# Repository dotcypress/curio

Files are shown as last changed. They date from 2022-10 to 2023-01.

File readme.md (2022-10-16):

# Curio

Glorified Infrared Remote Control.

## Resources

- [Schematics](docs/curio.pdf)
- [Gerber files](docs/curio_pcb_rev_0x02.zip)
- [Interactive BOM](https://htmlpreview.github.io/?https://github.com/dotcypress/curio/blob/main/docs/ibom.html)
- [Rust firmware](https://github.com/dotcypress/curio-firmware)

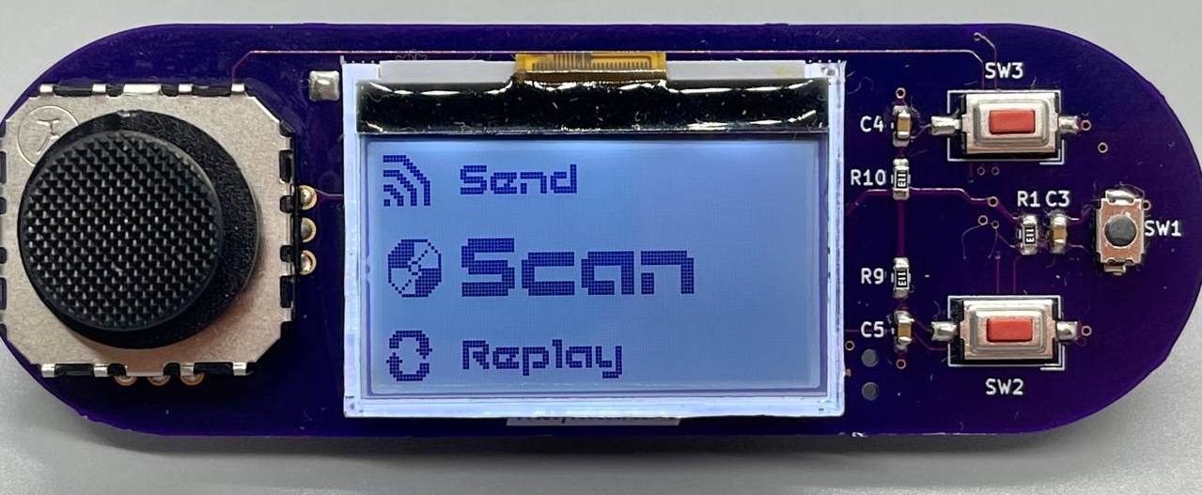
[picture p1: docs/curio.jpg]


## Credits

* [`1-Bit Icons`](https://vectorpixelstar.itch.io) by VectorPixelStar
* [`Edition 12`](https://www.dafont.com/edition-12.font) font by Designer's High
* [`BM Army`](https://www.dafont.com/bm-army.font) font by BitmapMania
* [`Nokia Cellphone FC`](https://www.dafont.com/nokia-cellphone.font) font by Zeh Fernando

## License

Licensed under either of

- Apache License, Version 2.0 ([LICENSE-APACHE](LICENSE-APACHE) or
  http://www.apache.org/licenses/LICENSE-2.0)
- MIT license ([LICENSE-MIT](LICENSE-MIT) or http://opensource.org/licenses/MIT)

at your option.

### Contribution

Unless you explicitly state otherwise, any contribution intentionally submitted
for inclusion in the work by you, as defined in the Apache-2.0 license, shall be
dual licensed as above, without any additional terms or conditions.

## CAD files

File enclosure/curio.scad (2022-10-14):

module Pcb(height=1.6) {
  length = 76.55;
  width = 25.451;

  translate([-length/2, -width/2, -height/2])
    hull()
      linear_extrude(height=height, convexity=8) 
      import(file="curio.svg");

  translate([-length/2 + 11.53, 0, 5])
    cube([10, 10, 10], center=true);
}

Pcb();

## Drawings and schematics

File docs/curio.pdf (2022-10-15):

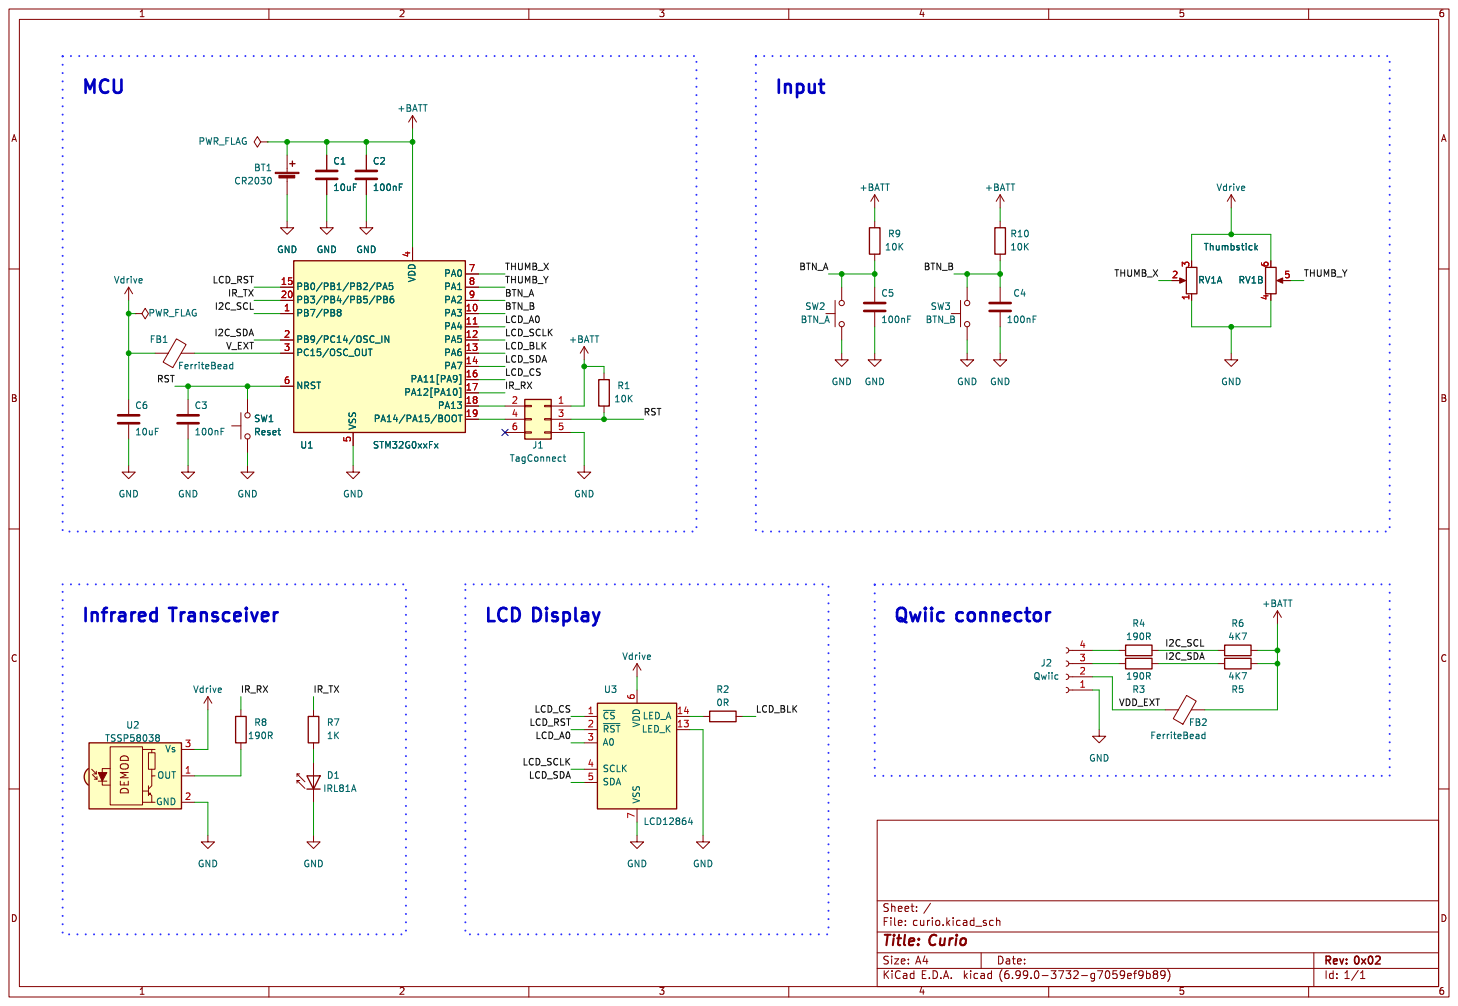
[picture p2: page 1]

5 NRST 6 PA0 7 PA1 8 PA2 9 U1 STM32G0xxFx DEMOD OUT 1 GND 2 Vs 3 U2 TSSP58038 Vdrive GND GND

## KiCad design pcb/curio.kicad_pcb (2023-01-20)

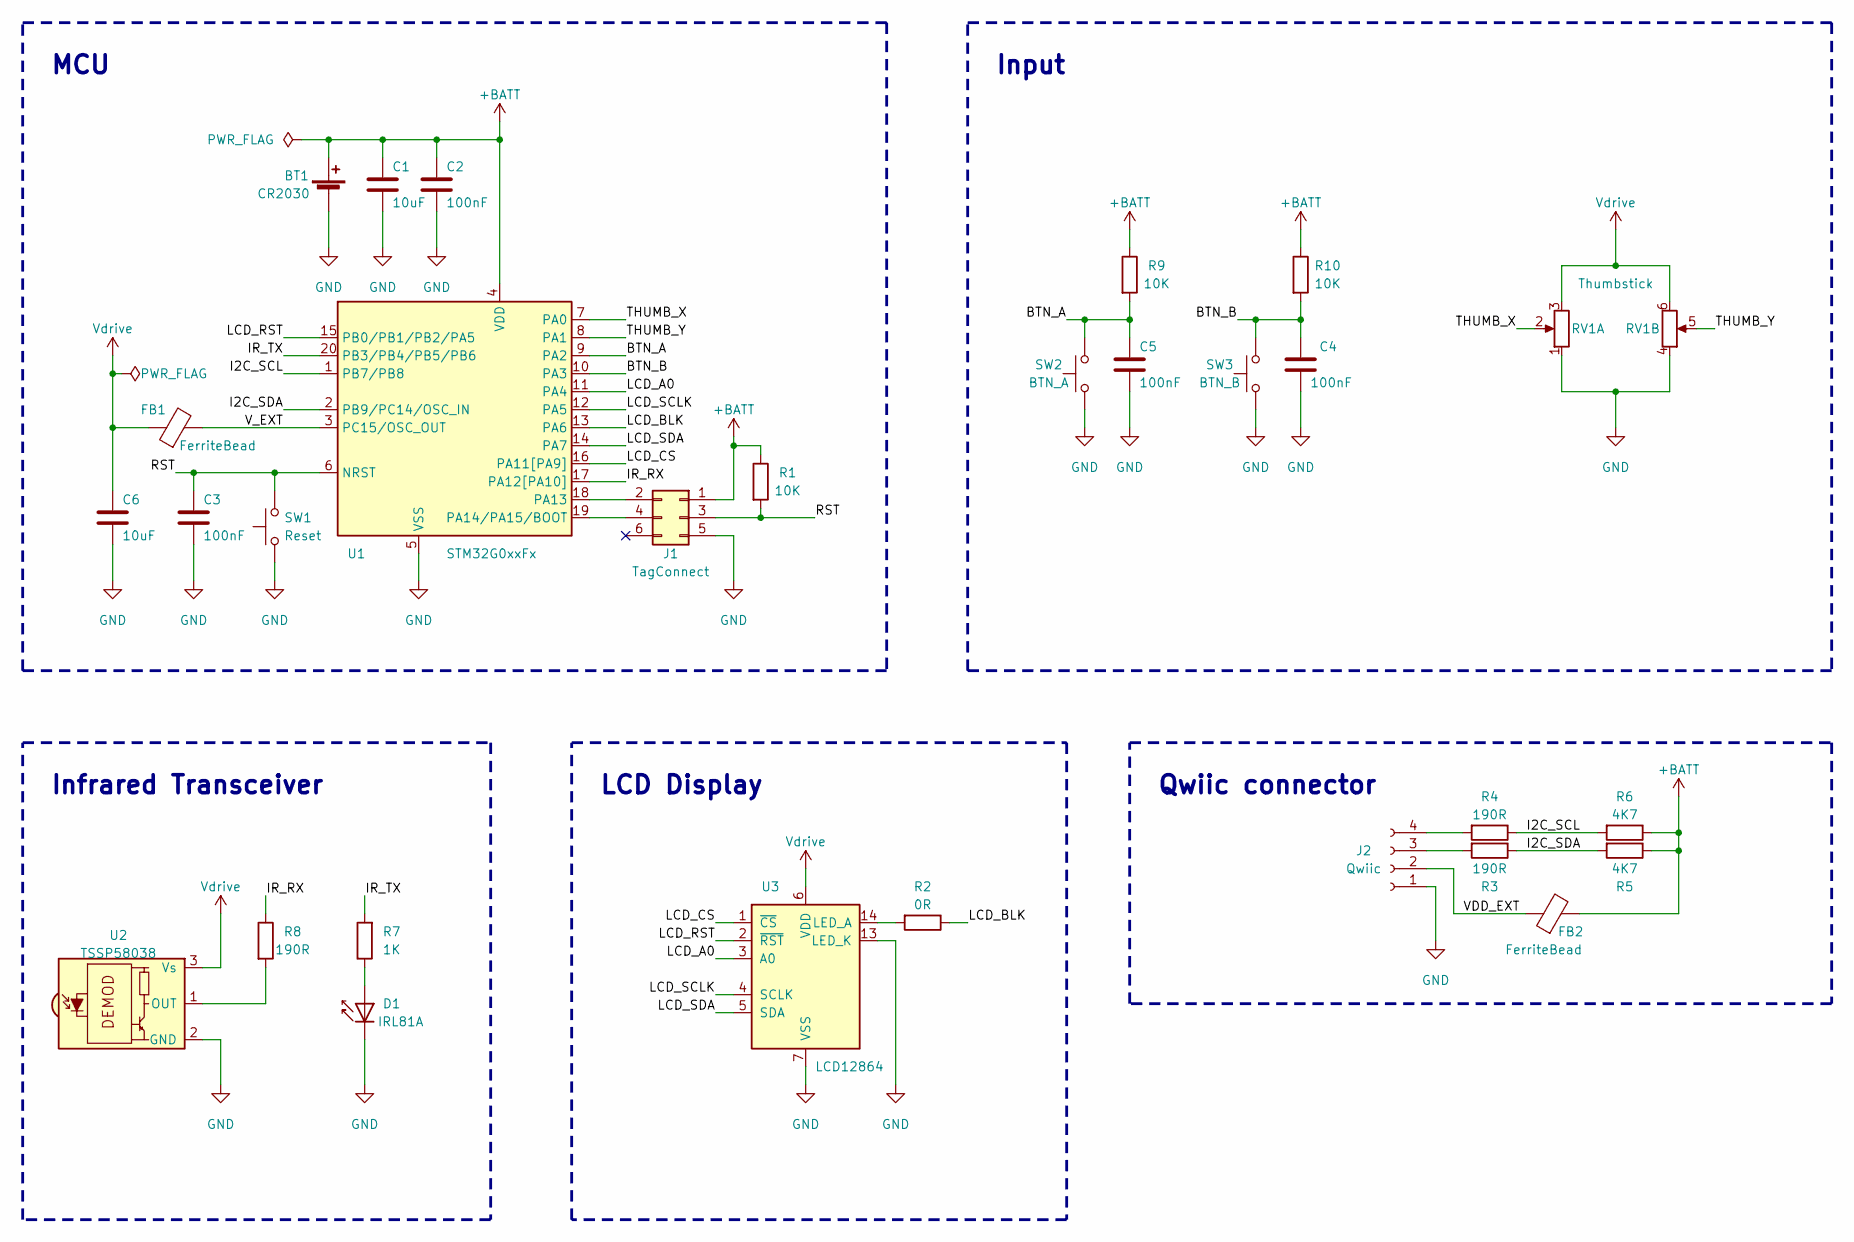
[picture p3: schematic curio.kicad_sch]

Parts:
BT1: CR2030; BatteryHolder-Lynx-BAT-HLD-001
C1, C6: 10uF; C_0603_1608Metric
C2, C3, C4, C5: 100nF; C_0603_1608Metric
D1: IRL81A; LED_SideEmitter_Rectangular_W4.5mm_H1.6mm
FB1, FB2: FerriteBead; R_0603_1608Metric
J1: TagConnect; Tag-Connect_TC2030-IDC-NL_2x03_P1.27mm_Vertical
J2: Qwiic; JST_SH_SM04B-SRSS-TB_1x04-1MP_P1.00mm_Horizontal
R1, R9, R10: 10K; R_0603_1608Metric
R2: 0R; R_0603_1608Metric
R3, R4, R8: 190R; R_0603_1608Metric
R5, R6: 4K7; R_0603_1608Metric
R7: 1K; R_0603_1608Metric
RV1: Thumbstick
SW1: Reset; R_1206_3216Metric_Pad1.30x1.75mm_HandSolder
SW2: BTN_A; SW_DIP_SPSTx01_Slide_6.7x4.1mm_W6.73mm_P2.54mm_LowProfile_J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
SW3: BTN_B; SW_DIP_SPSTx01_Slide_6.7x4.1mm_W6.73mm_P2.54mm_LowProfile_J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
U1: STM32G0xxFx; TSSOP-20_4.4x6.5mm_P0.65mm
U2: TSSP58038; Vishay_MINICAST-3Pin
U3: LCD12864; LCD_FPC_1x14_P0.80mm

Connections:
+BATT: BT1.1 (+), C1.1, C2.1, FB2.2, J1.1, R1.1, R5.1, R6.1, R9.1, R10.1, U1.4 (VDD)
/BTN_A: C5.1, R9.2, SW2.2, U1.9 (PA2)
/BTN_B: C4.1, R10.2, SW3.2, U1.10 (PA3)
/I2C_SCL: R4.1, R6.2, U1.1 (PB7/PB8)
/I2C_SDA: R3.1, R5.2, U1.2 (PB9/PC14/OSC_IN)
/IR_RX: R8.1, U1.17 (PA12[PA10])
/IR_TX: R7.2, U1.20 (PB3/PB4/PB5/PB6)
/LCD_A0: U1.11 (PA4), U3.3 (A0)
/LCD_BLK: R2.1, U1.13 (PA6)
/LCD_CS: U1.16 (PA11[PA9]), U3.1 (~CS)
/LCD_RST: U1.15 (PB0/PB1/PB2/PA5), U3.2 (~RST)
/LCD_SCLK: U1.12 (PA5), U3.4 (SCLK)
/LCD_SDA: U1.14 (PA7), U3.5 (SDA)
/RST: C3.1, J1.3, R1.2, SW1.2, U1.6 (NRST)
/THUMB_X: RV1.2, U1.7 (PA0)
/THUMB_Y: RV1.5, U1.8 (PA1)
/VDD_EXT: FB2.1, J2.2
/V_EXT: FB1.2, U1.3 (PC15/OSC_OUT)
GND: BT1.2 (-), C1.2, C2.2, C3.2, C4.2, C5.2, C6.2, D1.1 (K), J1.5, J2.1, RV1.1, RV1.4, SW1.1, SW2.1, SW3.1, U1.5 (VSS), U2.2 (GND), U3.7 (VSS), U3.13 (LED_K)
unnamed: D1.2 (A), R7.1
unnamed: J1.2, U1.18 (PA13)
unnamed: J1.4, U1.19 (PA14/PA15/BOOT)
unnamed: J2.3, R3.2
unnamed: J2.4, R4.2
unnamed: R8.2, U2.1 (OUT)
unnamed: R2.2, U3.14 (LED_A)
Vdrive: C6.1, FB1.1, RV1.3, RV1.6, U2.3 (Vs), U3.6 (VDD)

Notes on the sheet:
Input
MCU
Qwiic connector
LCD Display
Infrared Transceiver

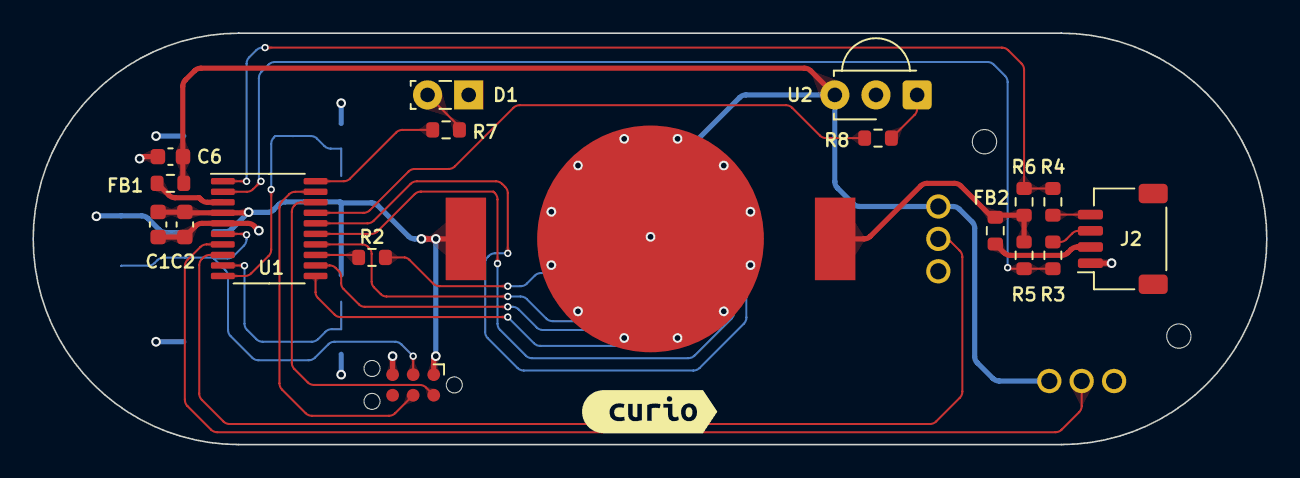
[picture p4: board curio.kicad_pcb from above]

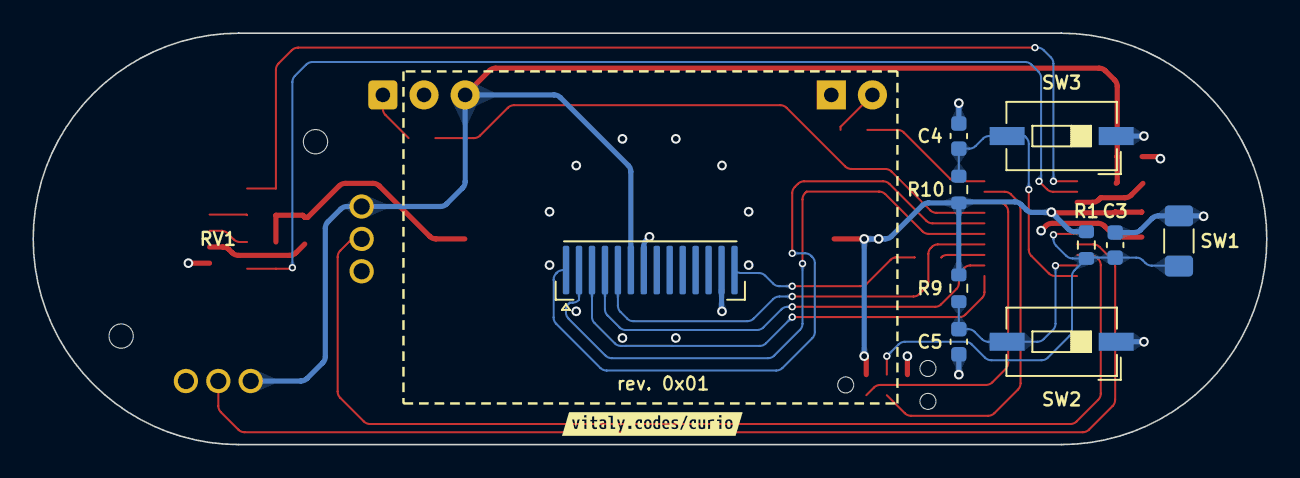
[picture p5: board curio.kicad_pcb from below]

Board: 4 copper layers, 76.2 x 25.4 mm, 31 parts (12 on the bottom side), 27 nets.

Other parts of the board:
kibuzzard-633E88B5: G***; kibuzzard-633E88B5
kibuzzard-633E88FC: G***; kibuzzard-633E88FC

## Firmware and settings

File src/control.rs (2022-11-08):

use crate::*;
use hal::analog::adc;

#[derive(Debug)]
pub enum Button {
    A,
    B,
    Up,
    Right,
    Down,
    Left,
}

pub struct Control {
    adc: adc::Adc,
    vbat: adc::VBat,
    btn_a: ButtonA,
    btn_b: ButtonB,
    thumb_x: ThumbX,
    thumb_y: ThumbY,
}

impl Control {
    pub fn new(
        btn_a: ButtonA,
        btn_b: ButtonB,
        thumb_x: ThumbX,
        thumb_y: ThumbY,
        adc: ADC,
        rcc: &mut Rcc,
    ) -> Self {
        let mut adc = adc.constrain(rcc);
        adc.set_sample_time(adc::SampleTime::T_80);
        adc.set_precision(adc::Precision::B_12);
        adc.set_oversampling_shift(24);
        adc.set_oversampling_ratio(adc::OversamplingRatio::X_8);
        adc.oversampling_enable(true);

        let mut vbat = adc::VBat::new();
        vbat.enable(&mut adc);

        adc.calibrate();
        Self {
            vbat,
            btn_a,
            btn_b,
            adc,
            thumb_x,
            thumb_y,
        }
    }

    pub fn battery_voltage(&mut self) -> u16 {
        self.adc.read_voltage(&mut self.vbat).unwrap_or_default() * 3
    }

    pub fn read_buttons(&mut self) -> Option<Button> {
        if self.btn_a.is_low().unwrap_or_default() {
            return Some(Button::A);
        }
        if self.btn_b.is_low().unwrap_or_default() {
            return Some(Button::B);
        }
        None
    }

    pub fn read_dpad(&mut self) -> Option<Button> {
        let (x, y) = self.read_thumb();
        if x > 32 {
            Some(Button::Right)
        } else if x < -32 {
            Some(Button::Left)
        } else if y > 32 {
            Some(Button::Up)
        } else if y < -32 {
            Some(Button::Down)
        } else {
            None
        }
    }

    pub fn read_thumb(&mut self) -> (i8, i8) {
        (
            self.adc.read(&mut self.thumb_x).unwrap_or(0) as i8 - 63,
            self.adc.read(&mut self.thumb_y).unwrap_or(0) as i8 - 63,
        )
    }
}

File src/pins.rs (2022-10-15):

use crate::hal::gpio::{gpioa::*, gpiob::*, gpioc::*};
use hal::gpio::{DefaultMode, Floating, Input, OpenDrain, Output, PushPull};
use hal::prelude::*;
use hal::rcc::Rcc;
use hal::stm32::*;

// Qwiic I2C
pub type I2cClk = PB8<Output<OpenDrain>>;
pub type I2cSda = PB9<Output<OpenDrain>>;

// Display
pub type LcdDC = PA4<Output<PushPull>>;
pub type LcdCS = PA11<Output<PushPull>>;
pub type LcdReset = PB0<Output<PushPull>>;
pub type LcdClk = PA5<DefaultMode>;
pub type LcdSda = PA7<DefaultMode>;
pub type LcdBacklight = PA6<DefaultMode>;

// Infared
pub type IrTx = PB6<DefaultMode>;
pub type IrRx = PA12<Input<Floating>>;

// Buttons
pub type ButtonA = PA2<Input<Floating>>;
pub type ButtonB = PA3<Input<Floating>>;

// Thumb
pub type ThumbX = PA1<DefaultMode>;
pub type ThumbY = PA0<DefaultMode>;

// DisplayPower
pub type DisplayPower = PC15<Output<PushPull>>;

// SWD
pub type SwdIo = PA13<DefaultMode>;
pub type SwdClk = PA14<DefaultMode>;

pub struct Pins {
    // SWD
    pub swd_io: SwdIo,
    pub swd_clk: SwdClk,

    // Qwiic I2C
    pub i2c_clk: I2cClk,
    pub i2c_sda: I2cSda,

    // Display
    pub lcd_reset: LcdReset,
    pub lcd_dc: LcdDC,
    pub lcd_cs: LcdCS,
    pub lcd_clk: LcdClk,
    pub lcd_sda: LcdSda,
    pub lcd_backlight: LcdBacklight,

    // Infared
    pub ir_tx: IrTx,
    pub ir_rx: IrRx,

    // Buttons
    pub btn_a: ButtonA,
    pub btn_b: ButtonB,

    // Thumb
    pub thumb_x: ThumbX,
    pub thumb_y: ThumbY,

    // Power
    pub lcd_power: DisplayPower,
}

impl Pins {
    pub fn new(gpioa: GPIOA, gpiob: GPIOB, gpioc: GPIOC, rcc: &mut Rcc) -> Self {
        let port_a = gpioa.split(rcc);
        let port_b = gpiob.split(rcc);
        let port_c = gpioc.split(rcc);

        Self {
            // SWD
            swd_io: port_a.pa13,
            swd_clk: port_a.pa14,

            // Qwiic I2C
            i2c_clk: port_b.pb8.into_open_drain_output_in_state(PinState::High),
            i2c_sda: port_b.pb9.into_open_drain_output_in_state(PinState::High),

            // Display
            lcd_reset: port_b.pb0.into(),
            lcd_dc: port_a.pa4.into(),
            lcd_cs: port_a.pa11.into(),
            lcd_clk: port_a.pa5,
            lcd_sda: port_a.pa7,
            lcd_backlight: port_a.pa6,

            // Infared
            ir_tx: port_b.pb6,
            ir_rx: port_a.pa12.into(),

            // Buttons
            btn_a: port_a.pa2.into(),
            btn_b: port_a.pa3.into(),

            // Thumb
            thumb_y: port_a.pa0,
            thumb_x: port_a.pa1,

            // Display Power
            lcd_power: port_c.pc15.into(),
        }
    }
}

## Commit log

2022-10-14 rev 0x02
    [curio.kicad_pcb, curio.kicad_sch, curio.scad]
2022-10-15 update bom
2022-10-15 rev. 0x02
    [curio.kicad_sch]
2022-10-16 update pcb photo
2022-10-17 updat wireframes
2022-11-06 ir samplerate config
2023-01-20 update hal version
    [curio.kicad_pcb, curio.kicad_sch]
